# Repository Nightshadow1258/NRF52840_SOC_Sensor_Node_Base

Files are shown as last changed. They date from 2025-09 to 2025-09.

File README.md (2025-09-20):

# NRF52840 SOC Sensor Node Base Board

# Version
release Version will be tracked by branches.
Each Version that is/will be produced will branch of main.
Main will always be the most recent version.

## V2.00
- Base Board for the [NRF52840_SOC](https://github.com/Nightshadow1258/NRF52840_SOC)
- changed connector to one with additional retention tabs to increase stability.

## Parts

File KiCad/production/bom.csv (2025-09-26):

Designator | Footprint | Quantity | Value | LCSC Part #
C221, C301, C304 | 0402 | 3 | 100nF | C1525
C302, C303, C307, C309 | 0402 | 4 | 1uF | C52923
C305, C306, C308 | 0603 | 3 | 10uF | C96446
CON101 | CON-GEN-USB_C-16P | 1 | G Switch GT USB 7010ASV | C2988369
CON102, CON103 | CON-SM02B-ZESS_TB | 2 | SM02B-ZESS-TB
D101 | SOT-23-6 | 1 | USBLC6-2 | C7519
D301 | 0603 | 1 | GREEN | C84267
D302 | 0603 | 1 | RED | C2286
FID101, FID102, FID103, FID104 | PCB-FID-JLCPCB | 4 | Fiducal-JLCPPCB
IC202 | DNF-1.5x1.5_H0.54-SHT40-AD1B_THPAD | 1 | IC_SENS-SHT40-AD1B_THP | C2848306
IC301 | WSON-6_1.5x1.5mm_P0.5mm | 1 | IC_PWREG-BQ29700 | C183096
IC302 | QFN-32-1EP_5x5mm_P0.5mm_EP3.6x3.6mm_ThermalVias | 1 | IC_PWREG-NPM1300
J201 | PinHeader_2x10_P2.54mm_Vertical | 1 | Conn_02x10_Odd_Even
L301 | L_0806 | 1 | 2.2uH | C2838367
M201 | M-NRF52840 | 1 | ~
MH101, MH102, MH103, MH104 | MountingHole_2.5mm_Pad_Via | 4 | ~
PCB101, PCB102, PCB103, PCB104 | PCB-NPTH-JLCPCB | 4 | Tooling Hole JLCPCB
R201, R306 | 0603 | 2 | 10k | C142556
R202, R301 | 0402 | 2 | 10k | C25744
R204, R206, R207, R208 | 0402 | 4 | 4k7 | C25900
R205, R210 | 0402 | 2 | 1M | C138033
R211 | 0402 | 1 | 750k | C137937
R302 | 0402 | 1 | 2k | C4109
R303 | 0402 | 1 | 330 | C25104
R304 | 0402 | 1 | 200k | C25764
R305 | 0402 | 1 | 0 | C17168
R307, R308 | 0402 | 2 | 1k | C11702
SW301 | SW-PUSH-DPST-XKS-TS-1187A | 1 | SW-GEN-TS-1187A | C318884
T301 | SOT-23 | 1 | SI2312BDS | C351405
T302 | SOT-23-6 | 1 | DMG6968UDM | C2762931
TP204, TP205, TP301, TP302, TP304, TP305, TP306, TP310 | TP_Pad_D0.9mm | 8 | TP
TP303, TP307, TP308, TP309 | TP_THT_D0.8mm | 4 | Testpoint-BASE

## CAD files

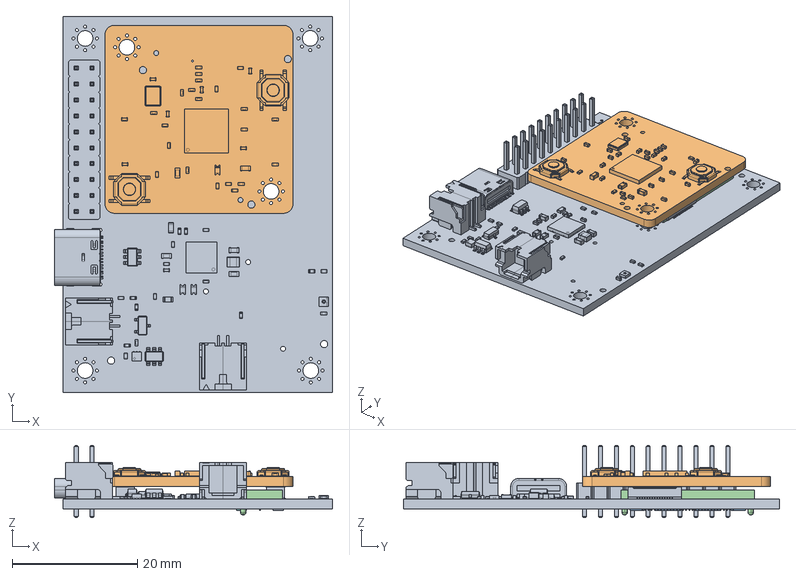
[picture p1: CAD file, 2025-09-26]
FreeCad/Board_Fit.FCStd
44.4 x 60.0 x 11.5 mm
QSH-030-01-L-D-A
QSH-030-01-L-D-A001
QSH-030-01-L-D-A002
QSH-030-01-L-D-A003
QSH-030-01-L-D-A004
QSH-030-01-L-D-A005
QSH-030-01-L-D-A006
QSH-030-01-L-D-A007
QSH-030-01-L-D-A008
QSH-030-01-L-D-A009
QSH-030-01-L-D-A010
QSH-030-01-L-D-A011
QSH-030-01-L-D-A012
QSH-030-01-L-D-A013
QSH-030-01-L-D-A014
QSH-030-01-L-D-A015
QSH-030-01-L-D-A016
QSH-030-01-L-D-A017
QSH-030-01-L-D-A018
QSH-030-01-L-D-A019
QSH-030-01-L-D-A020
QSH-030-01-L-D-A021
QSH-030-01-L-D-A022
QSH-030-01-L-D-A023
QSH-030-01-L-D-A024
QSH-030-01-L-D-A025
QSH-030-01-L-D-A026
QSH-030-01-L-D-A027
QSH-030-01-L-D-A028
QSH-030-01-L-D-A029
QSH-030-01-L-D-A030
QSH-030-01-L-D-A031
QSH-030-01-L-D-A032
QSH-030-01-L-D-A033
QSH-030-01-L-D-A034
QSH-030-01-L-D-A035
QSH-030-01-L-D-A036
QSH-030-01-L-D-A037
QSH-030-01-L-D-A038
QSH-030-01-L-D-A039
QSH-030-01-L-D-A040
QSH-030-01-L-D-A041
QSH-030-01-L-D-A042
QSH-030-01-L-D-A043
QSH-030-01-L-D-A044
QSH-030-01-L-D-A045
QSH-030-01-L-D-A046
QSH-030-01-L-D-A047
QSH-030-01-L-D-A048
QSH-030-01-L-D-A049
QSH-030-01-L-D-A050
QSH-030-01-L-D-A051
QSH-030-01-L-D-A052
QSH-030-01-L-D-A053
QSH-030-01-L-D-A054
QSH-030-01-L-D-A055
QSH-030-01-L-D-A056
QSH-030-01-L-D-A057
QSH-030-01-L-D-A058
QSH-030-01-L-D-A059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

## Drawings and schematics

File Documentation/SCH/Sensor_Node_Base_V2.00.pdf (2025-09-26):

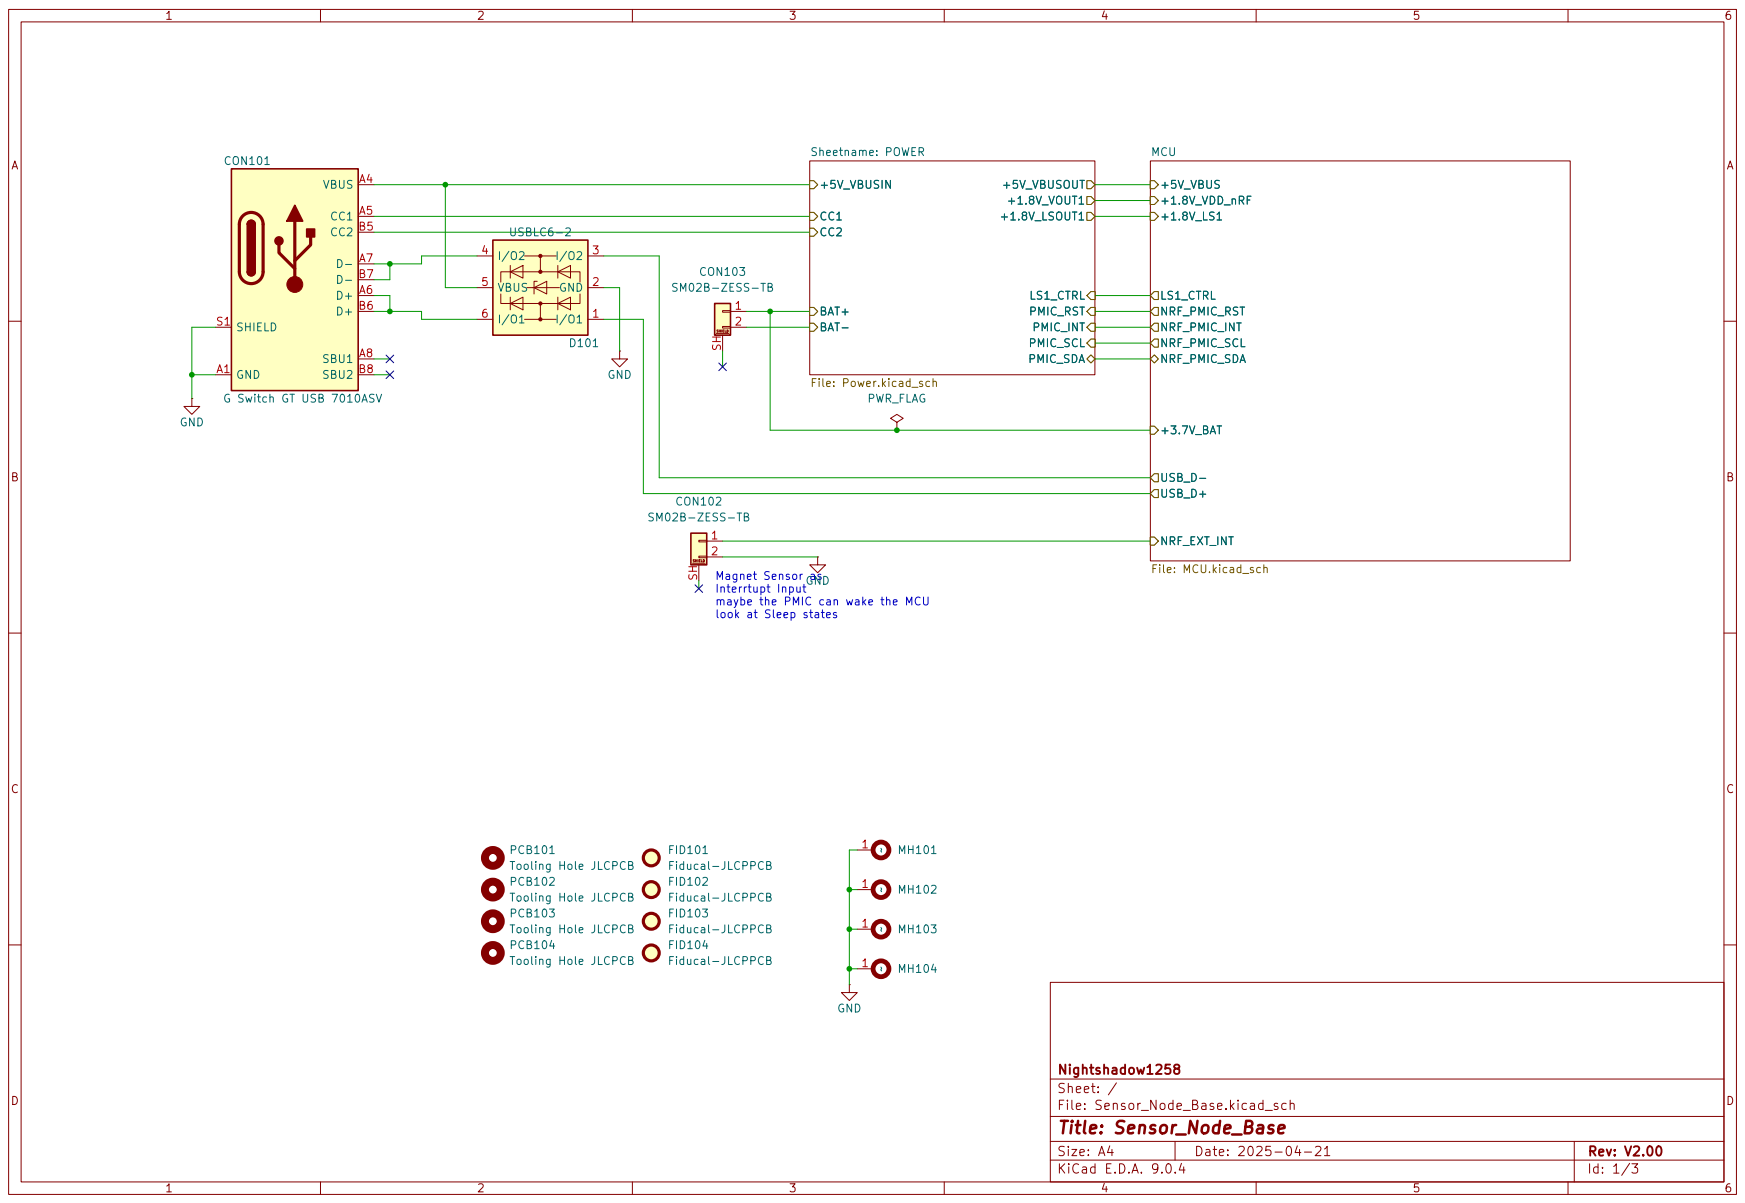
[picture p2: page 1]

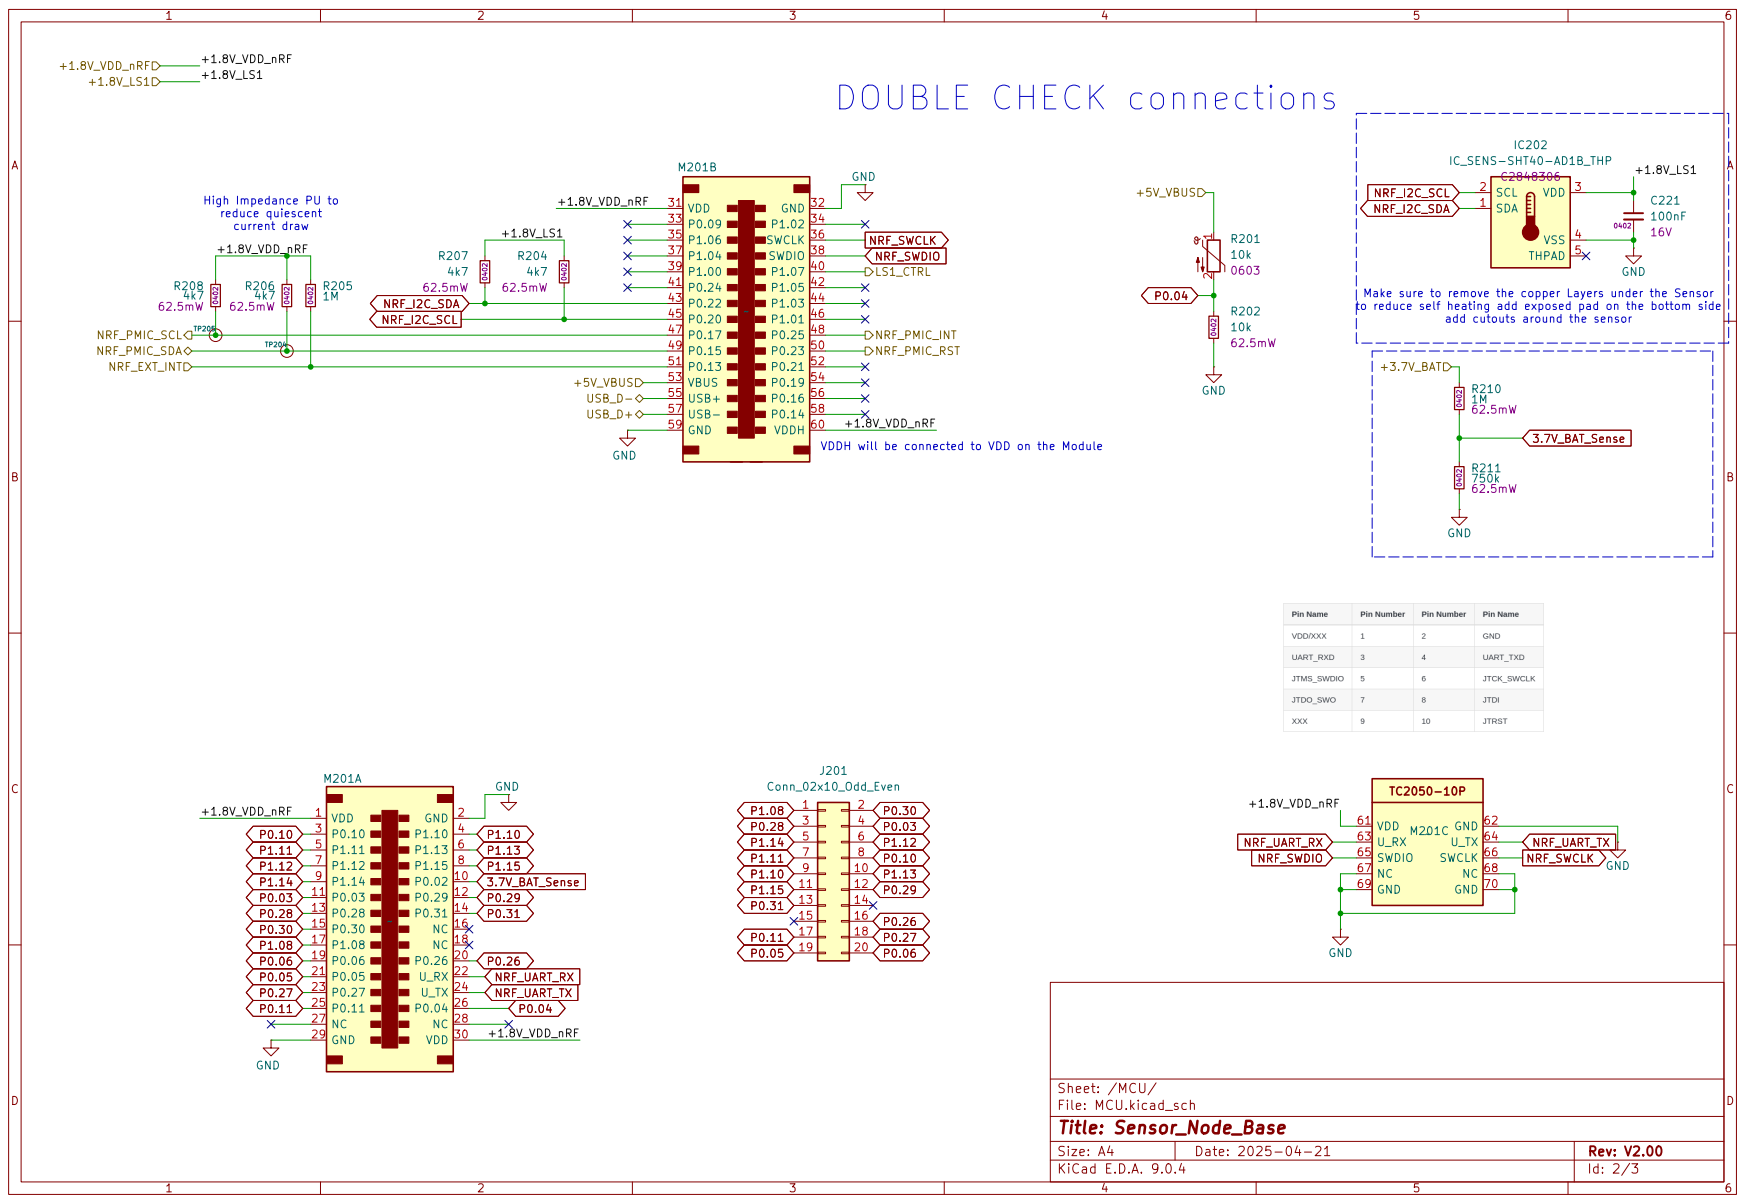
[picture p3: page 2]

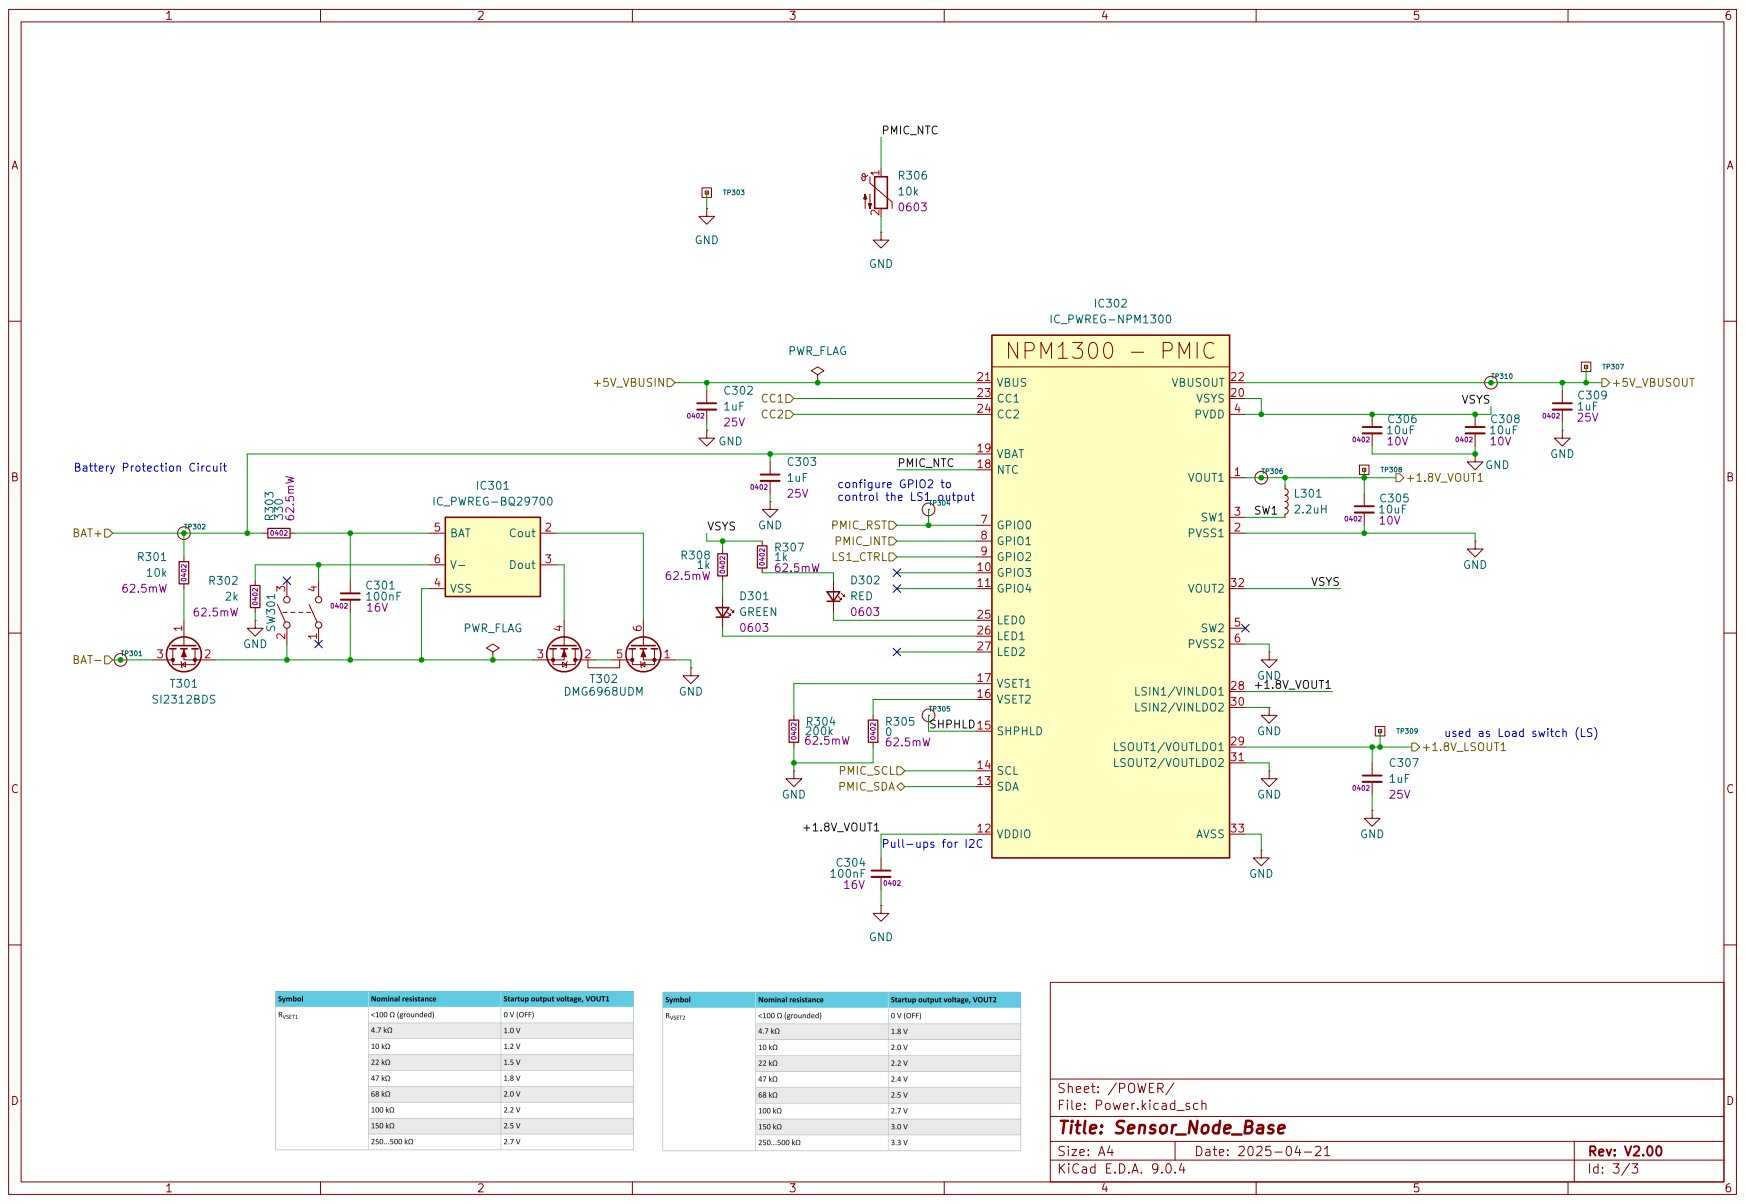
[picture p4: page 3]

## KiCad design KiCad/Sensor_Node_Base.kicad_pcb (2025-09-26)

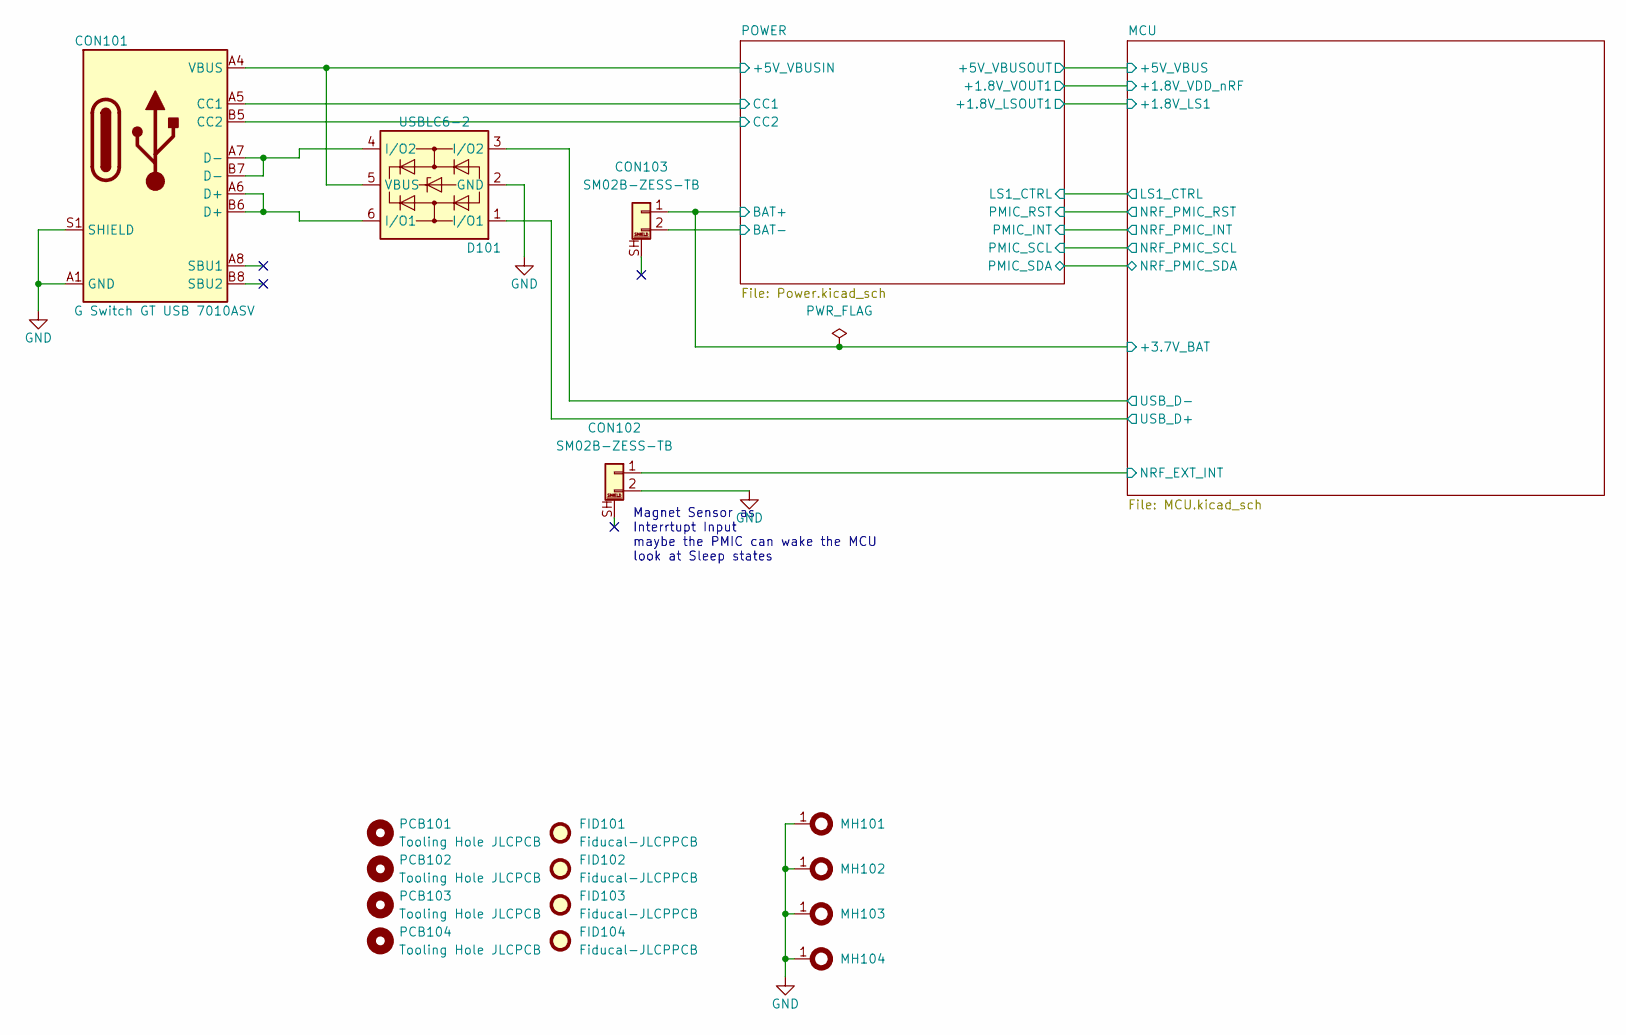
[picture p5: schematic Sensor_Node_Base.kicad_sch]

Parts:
CON101: G Switch GT USB 7010ASV; CON-GEN-USB_C-16P; LCSC Part # C2988369
CON102, CON103: SM02B-ZESS-TB; CON-SM02B-ZESS_TB
D101: USBLC6-2; SOT-23-6; LCSC Part # C7519
FID101, FID102, FID103, FID104: Fiducal-JLCPPCB; PCB-FID-JLCPCB
MH101, MH102, MH103, MH104: MountingHole_2.5mm_Pad_Via
PCB101, PCB102, PCB103, PCB104: Tooling Hole JLCPCB; PCB-NPTH-JLCPCB

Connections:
/MCU/+3.7V_BAT: CON103.1; also elsewhere on the board
/MCU/NRF_EXT_INT: CON102.1; also elsewhere on the board
/MCU/USB_D+: D101.1 (I/O1); also elsewhere on the board
/MCU/USB_D-: D101.3 (I/O2); also elsewhere on the board
/POWER/+5V_VBUSIN: CON101.A4 (VBUS), CON101.A9 (VBUS), CON101.B4 (VBUS), CON101.B9 (VBUS), D101.5 (VBUS); also elsewhere on the board
/POWER/BAT-: CON103.2; also elsewhere on the board
/POWER/CC1: CON101.A5 (CC1); also elsewhere on the board
/POWER/CC2: CON101.B5 (CC2); also elsewhere on the board
GND: CON101.A1 (GND), CON101.A12 (GND), CON101.B1 (GND), CON101.B12 (GND), CON101.S1 (SHIELD), CON102.2, D101.2 (GND), MH101.1, MH102.1, MH103.1, MH104.1; also elsewhere on the board
unnamed: CON101.A6 (D+), CON101.B6 (D+), D101.6 (I/O1)
unnamed: CON101.A7 (D-), CON101.B7 (D-), D101.4 (I/O2)

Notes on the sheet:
Magnet Sensor as Interrtupt Input maybe the PMIC can wake the MCU look at Sleep states

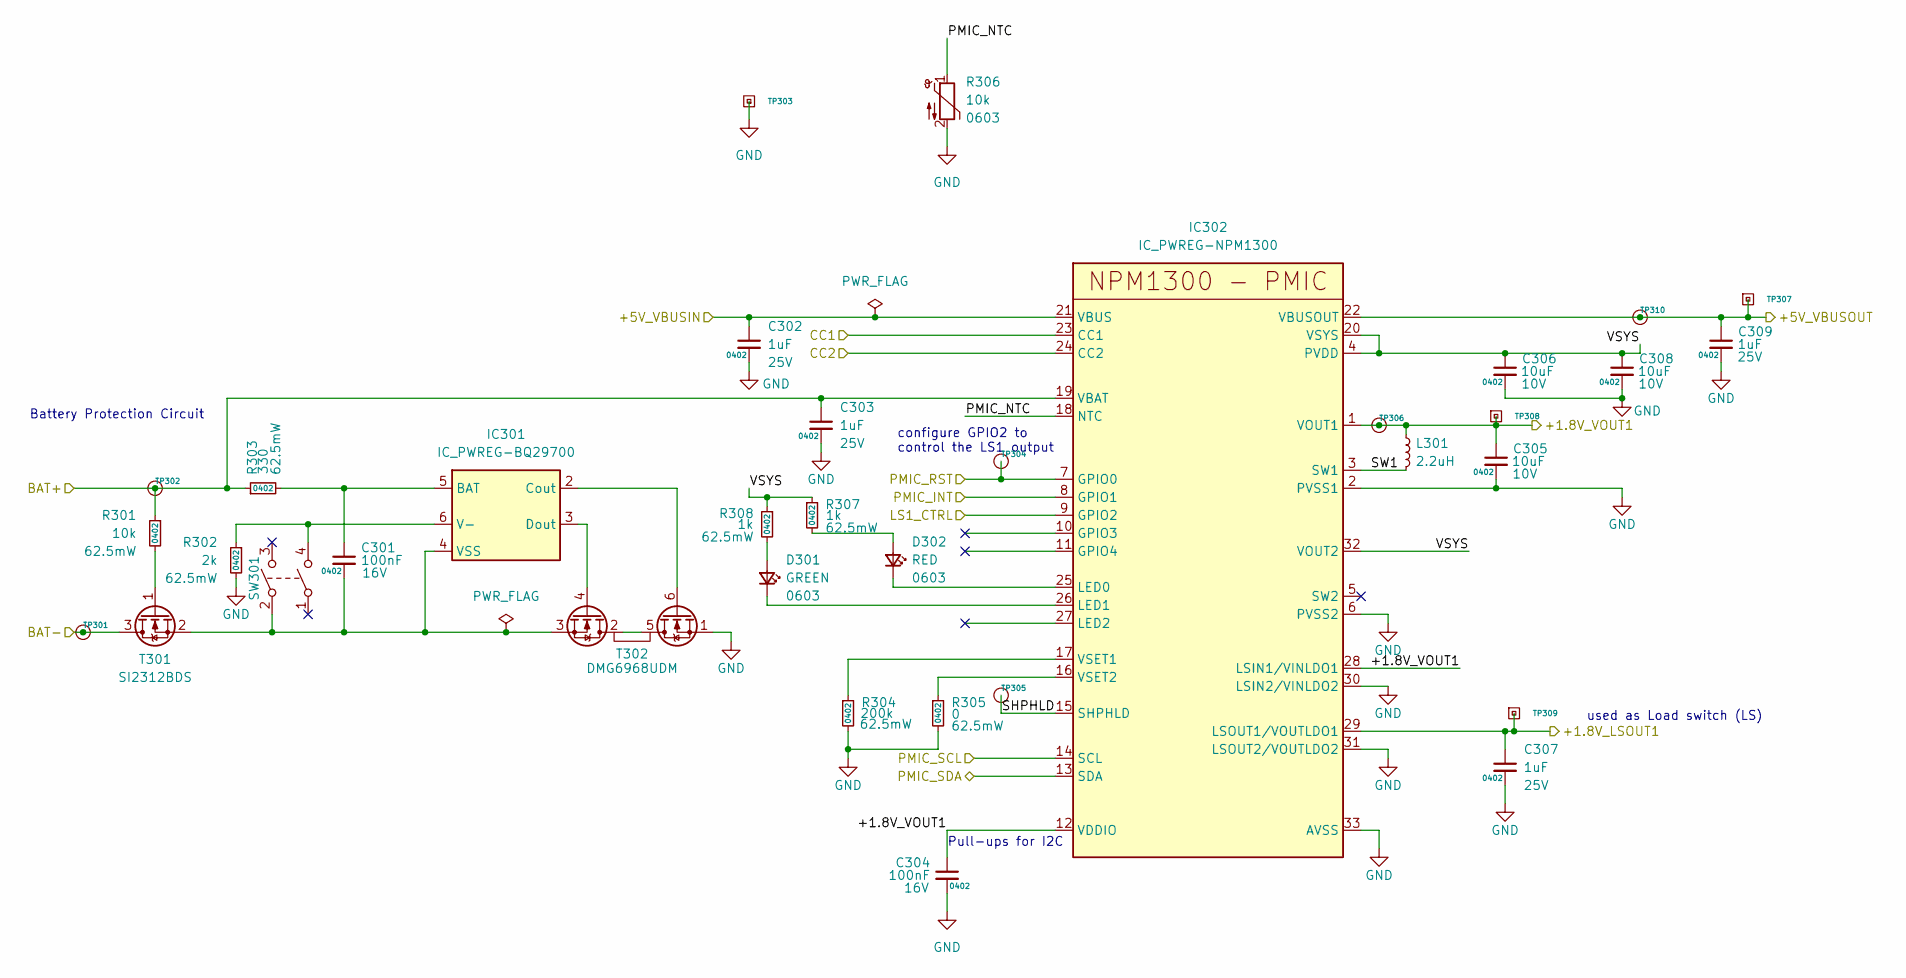
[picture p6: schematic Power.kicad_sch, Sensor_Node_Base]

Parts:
C301, C304: 100nF; C_0402_1005Metric; Voltage 16V; LCSC Part # C1525
C302, C303, C307, C309: 1uF; C_0402_1005Metric; Voltage 25V; LCSC Part # C52923
C305, C306, C308: 10uF; C_0603_1608Metric; Voltage 10V; LCSC Part # C96446
D301: GREEN; D_0603_1608Metric; LCSC Part # C84267
D302: RED; D_0603_1608Metric; LCSC Part # C2286
IC301: IC_PWREG-BQ29700; WSON-6_1.5x1.5mm_P0.5mm; LCSC Part # C183096
IC302: IC_PWREG-NPM1300; QFN-32-1EP_5x5mm_P0.5mm_EP3.6x3.6mm_ThermalVias
L301: 2.2uH; L_0806; LCSC Part # C2838367
R301: 10k; R_0402_1005Metric; Power Rating 62.5mW; LCSC Part # C25744
R302: 2k; R_0402_1005Metric; Power Rating 62.5mW; LCSC Part # C4109
R303: 330; R_0402_1005Metric; Power Rating 62.5mW; LCSC Part # C25104
R304: 200k; R_0402_1005Metric; Power Rating 62.5mW; LCSC Part # C25764
R305: 0; R_0402_1005Metric; Power Rating 62.5mW; LCSC Part # C17168
R306: 10k; R_0603_1608Metric; LCSC Part # C142556
R307, R308: 1k; R_0402_1005Metric; Power Rating 62.5mW; LCSC Part # C11702
SW301: SW-GEN-TS-1187A; SW-PUSH-DPST-XKS-TS-1187A; LCSC Part # C318884
T301: SI2312BDS; SOT-23; LCSC Part # C351405
T302: DMG6968UDM; SOT-23-6; LCSC Part # C2762931
TP301, TP302, TP304, TP305, TP306, TP310: TP; TP_Pad_D0.9mm
TP303, TP307, TP308, TP309: Testpoint-BASE; TP_THT_D0.8mm

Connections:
/MCU/+1.8V_LS1: C307.1, IC302.29 (LSOUT1/VOUTLDO1), TP309.1; also elsewhere on the board
/MCU/+1.8V_VDD_nRF: C304.1, C305.1, IC302.1 (VOUT1), IC302.12 (VDDIO), IC302.28 (LSIN1/VINLDO1), L301.1, TP306.1, TP308.1; also elsewhere on the board
/MCU/+3.7V_BAT: C303.1, IC302.19 (VBAT), R301.1, R303.1, TP302.1; also elsewhere on the board
/MCU/+5V_VBUS: C309.1, IC302.22 (VBUSOUT), TP307.1, TP310.1; also elsewhere on the board
/MCU/LS1_CTRL: IC302.9 (GPIO2); also elsewhere on the board
/MCU/NRF_PMIC_INT: IC302.8 (GPIO1); also elsewhere on the board
/MCU/NRF_PMIC_RST: IC302.7 (GPIO0), TP304.1; also elsewhere on the board
/MCU/NRF_PMIC_SCL: IC302.14 (SCL); also elsewhere on the board
/MCU/NRF_PMIC_SDA: IC302.13 (SDA); also elsewhere on the board
/POWER/+5V_VBUSIN: C302.1, IC302.21 (VBUS); also elsewhere on the board
/POWER/BAT-: T301.3 (D), TP301.1; also elsewhere on the board
/POWER/CC1: IC302.23 (CC1); also elsewhere on the board
/POWER/CC2: IC302.24 (CC2); also elsewhere on the board
/POWER/PMIC_NTC: IC302.18 (NTC), R306.1
/POWER/SHPHLD: IC302.15 (SHPHLD), TP305.1
/POWER/SW1: IC302.3 (SW1), L301.2
/POWER/VSYS: C306.1, C308.1, IC302.4 (PVDD), IC302.20 (VSYS), IC302.32 (VOUT2), R307.1, R308.1
GND: C302.2, C303.2, C304.2, C305.2, C306.2, C307.2, C308.2, C309.2, IC302.2 (PVSS1), IC302.6 (PVSS2), IC302.30 (LSIN2/VINLDO2), IC302.31 (LSOUT2/VOUTLDO2), IC302.33 (AVSS), R302.2, R304.2, R305.2, R306.2, T302.1 (S1), TP303.1; also elsewhere on the board
unnamed: D301.2 (A), R308.2
unnamed: D301.1 (K), IC302.26 (LED1)
unnamed: D302.2 (A), R307.2
unnamed: D302.1 (K), IC302.25 (LED0)
unnamed: C301.1, IC301.5 (BAT), R303.2
unnamed: IC301.2 (Cout), T302.6 (G1)
unnamed: IC301.3 (Dout), T302.4 (G2)
unnamed: IC301.6 (V-), R302.1, SW301.4
unnamed: C301.2, IC301.4 (VSS), SW301.2 (3), T301.2 (S), T302.3 (S2)
unnamed: IC302.17 (VSET1), R304.1
unnamed: IC302.16 (VSET2), R305.1
unnamed: R301.2, T301.1 (G)
unnamed: T302.2 (D1/D2), T302.5 (D1/D2)

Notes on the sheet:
Battery Protection Circuit
used as Load switch (LS)
configure GPIO2 to control the LS1 output
Pull-ups for I2C

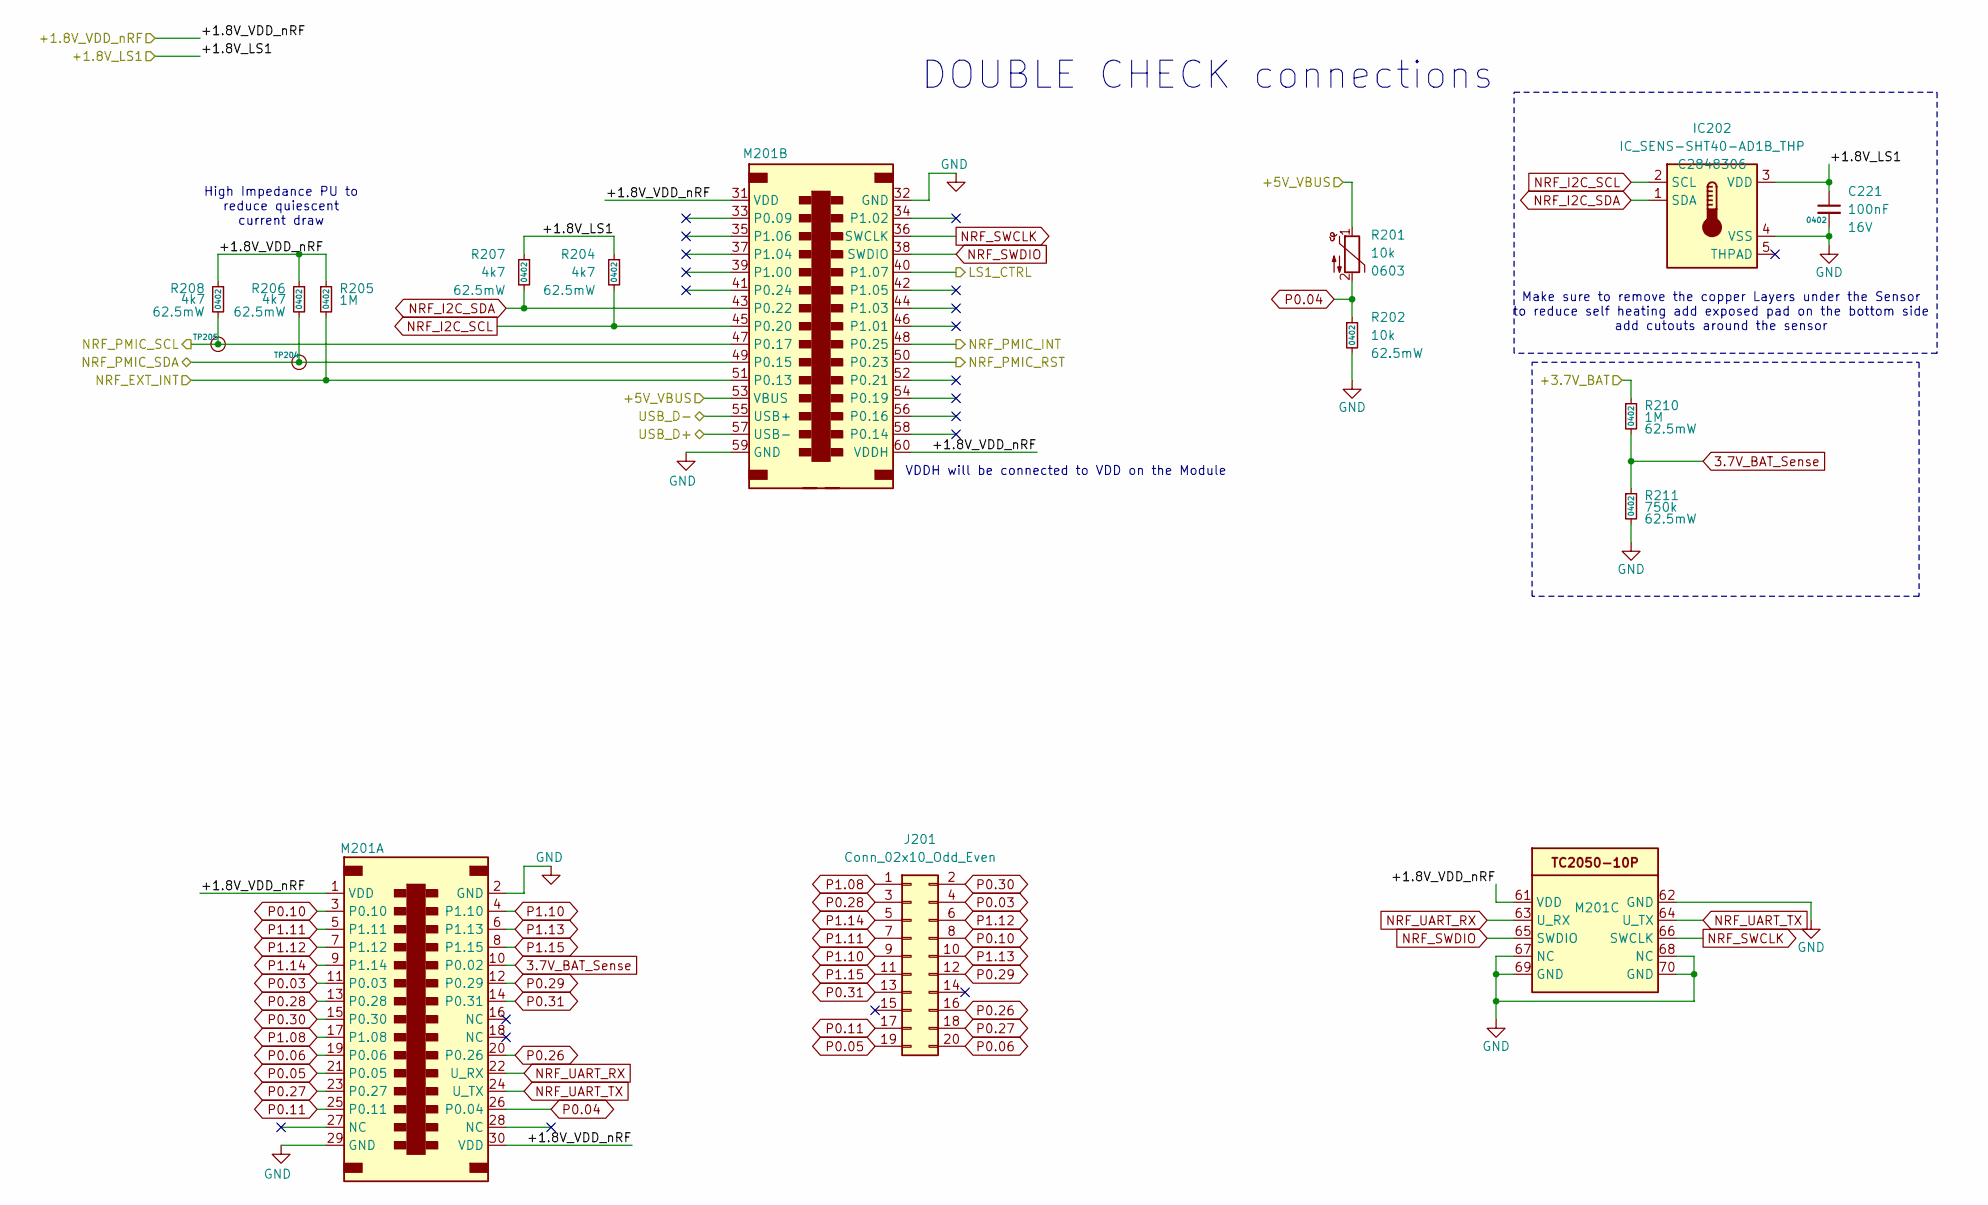
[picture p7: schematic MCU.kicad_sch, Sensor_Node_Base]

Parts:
C221: 100nF; C_0402_1005Metric; Voltage 16V; LCSC Part # C1525
IC202: IC_SENS-SHT40-AD1B_THP; DNF-1.5x1.5_H0.54-SHT40-AD1B_THPAD; LCSC Part # C2848306
J201: Conn_02x10_Odd_Even; PinHeader_2x10_P2.54mm_Vertical
M201: M-NRF52840
R201: 10k; R_0603_1608Metric; LCSC Part # C142556
R202: 10k; R_0402_1005Metric; Power Rating 62.5mW; LCSC Part # C25744
R204, R206, R207, R208: 4k7; R_0402_1005Metric; Power Rating 62.5mW; LCSC Part # C25900
R205, R210: 1M; R_0402_1005Metric; Power Rating 62.5mW; LCSC Part # C138033
R211: 750k; R_0402_1005Metric; Power Rating 62.5mW; LCSC Part # C137937
TP204, TP205: TP; TP_Pad_D0.9mm

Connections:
3.7V_BAT_Sense: M201.10 (P0.02), R210.2, R211.1
/MCU/+1.8V_LS1: C221.1, IC202.3 (VDD), R204.1, R207.1; also elsewhere on the board
/MCU/+1.8V_VDD_nRF: M201.1 (VDD), M201.30 (VDD), M201.31 (VDD), M201.60 (VDDH), M201.61 (VDD), R205.1, R206.1, R208.1; also elsewhere on the board
/MCU/+3.7V_BAT: R210.1; also elsewhere on the board
/MCU/+5V_VBUS: M201.53 (VBUS), R201.1; also elsewhere on the board
/MCU/LS1_CTRL: M201.40 (P1.07); also elsewhere on the board
/MCU/NRF_EXT_INT: M201.51 (P0.13), R205.2; also elsewhere on the board
/MCU/NRF_PMIC_INT: M201.48 (P0.25); also elsewhere on the board
/MCU/NRF_PMIC_RST: M201.50 (P0.23); also elsewhere on the board
/MCU/NRF_PMIC_SCL: M201.47 (P0.17), R208.2, TP205.1; also elsewhere on the board
/MCU/NRF_PMIC_SDA: M201.49 (P0.15), R206.2, TP204.1; also elsewhere on the board
/MCU/USB_D+: M201.57 (USB-); also elsewhere on the board
/MCU/USB_D-: M201.55 (USB+); also elsewhere on the board
GND: C221.2, IC202.4 (VSS), M201.2 (GND), M201.29 (GND), M201.32 (GND), M201.59 (GND), M201.62 (GND), M201.67 (NC), M201.68 (NC), M201.69 (GND), M201.70 (GND), R202.2, R211.2; also elsewhere on the board
NRF_I2C_SCL: IC202.2 (SCL), M201.45 (P0.20), R204.2
NRF_I2C_SDA: IC202.1 (SDA), M201.43 (P0.22), R207.2
NRF_SWCLK: M201.36 (SWCLK), M201.66 (SWCLK)
NRF_SWDIO: M201.38 (SWDIO), M201.65 (SWDIO)
NRF_UART_RX: M201.22 (U_RX), M201.63 (U_RX)
NRF_UART_TX: M201.24 (U_TX), M201.64 (U_TX)
P0.03: J201.4, M201.11 (P0.03)
P0.04: M201.26 (P0.04), R201.2, R202.1
P0.05: J201.19, M201.21 (P0.05)
P0.06: J201.20, M201.19 (P0.06)
P0.10: J201.8, M201.3 (P0.10)
P0.11: J201.17, M201.25 (P0.11)
P0.26: J201.16, M201.20 (P0.26)
P0.27: J201.18, M201.23 (P0.27)
P0.28: J201.3, M201.13 (P0.28)
P0.29: J201.12, M201.12 (P0.29)
P0.30: J201.2, M201.15 (P0.30)
P0.31: J201.13, M201.14 (P0.31)
P1.08: J201.1, M201.17 (P1.08)
P1.10: J201.9, M201.4 (P1.10)
P1.11: J201.7, M201.5 (P1.11)
P1.12: J201.6, M201.7 (P1.12)
P1.13: J201.10, M201.6 (P1.13)
P1.14: J201.5, M201.9 (P1.14)
P1.15: J201.11, M201.8 (P1.15)

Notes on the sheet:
VDDH will be connected to VDD on the Module
High Impedance PU to reduce quiescent current draw
DOUBLE CHECK connections
Make sure to remove the copper Layers under the Sensor to reduce self heating add exposed pad on the bottom side add cutouts around the sensor

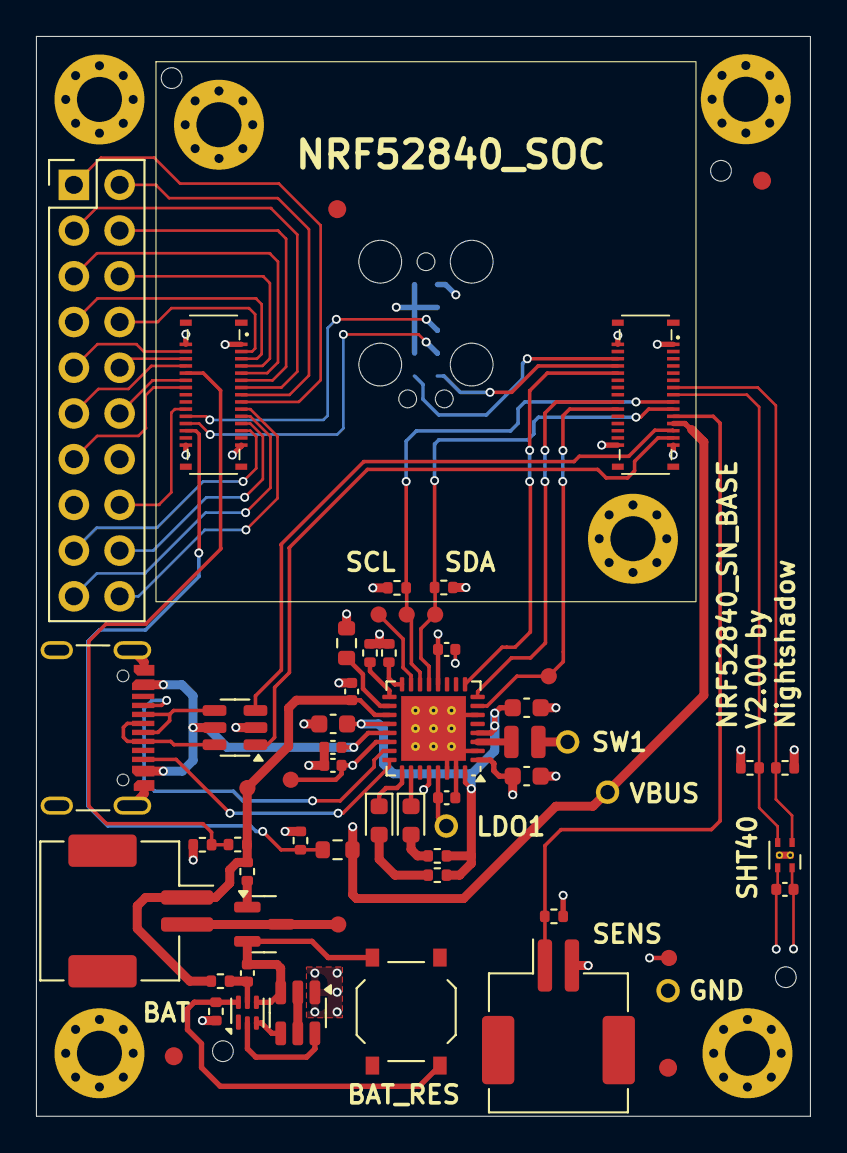
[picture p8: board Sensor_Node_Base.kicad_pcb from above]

Board: 4 copper layers, 43.0 x 60.0 mm, 66 parts (0 on the bottom side), 62 nets.

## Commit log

2025-09-20 V1.00 commit
    [Board_Fit.FCStd, MCU.kicad_sch, Power.kicad_sch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]
2025-09-20 rename to generic name
    [MCU.kicad_sch, Power.kicad_sch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]
2025-09-26 added button to reset the battery proteciton.
    [Board_Fit.FCStd, Power.kicad_sch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]
